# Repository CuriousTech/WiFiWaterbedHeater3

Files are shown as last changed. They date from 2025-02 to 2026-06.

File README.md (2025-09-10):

# WiFi Waterbed Heater 3 (final)

This is the 3rd and final iteration of this. The GUI is based on my [Universal Remote](https://github.com/CuriousTech/Smart-Universal-Remote) so it has a multi-tile swap gesture interface using the
[WaveShare-ESP32-S3-Touch-LCD-2.8](https://www.waveshare.com/wiki/ESP32-S3-Touch-LCD-2.8).  
  
wb3  
  
The small breakout board is not really needed and uses more space since the only component required is a 4K7 resistor to pull up the DS18B20 signal line, but I already have connectors for everything from the old project. So from left to right: DS18B20, power/slave, LD2410, and AM2320/AM2322 vertically.  The i2c lines have internal pullups.  
  
WBBOB  
  
The slave board and 3D files from the WB2 project is reposted here as well.  
  
3D  

The web page. Same as previous, but allows drag and drop files over the lower file display areas. The internal files are only used for click and notifications sounds so far. It's just easier than setting up to upload the FFat.  Although SPIFFS or LittleFS can be used instead very easily. The SD card is used for the MP3 player.  
  
Web  
  
Building: The ino explains the common settings for the IDE like my other projects. I use the Windows Store version because it works best for me. If a library is missing, the error should show a line with a link to where to get it. If not, complain.  
  
A little explanation of the HLK-LD2450 reader: The bottom area of the page represents the detection area. The 5000 (mm) is the X (signed X/2) and Y cutoff. Anything beyond that is zone 2 (outside the room). Zone 2 is also anything painted grey (this sees through walls). This area means lights/fan off. Zome 1 is in the room/lights on and fan off, motion or not. Latch area switches to zone 0/light off and fan on. Hold area is still in bed/zone 0 if latched.

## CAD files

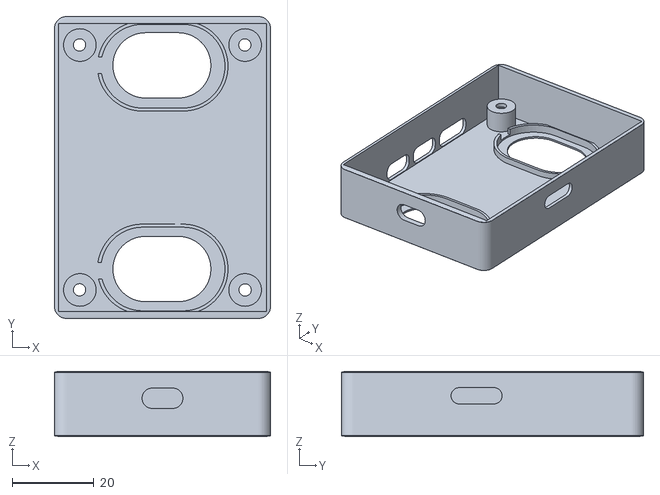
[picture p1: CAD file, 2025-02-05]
3D/WaveShare28wb.stl
53.0 x 74.0 x 16.0

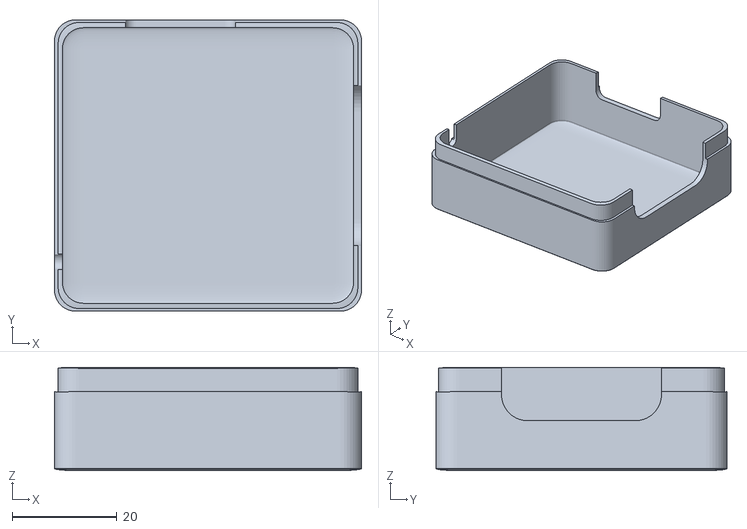
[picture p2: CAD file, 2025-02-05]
3D/Slave Bottom.stl
58.5 x 55.5 x 19.7

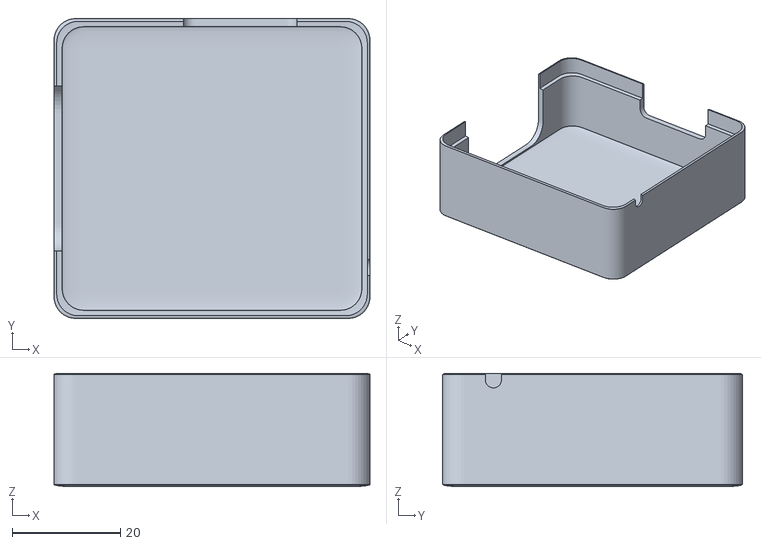
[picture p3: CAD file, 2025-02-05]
3D/Slave Top.stl
58.5 x 55.5 x 21.0

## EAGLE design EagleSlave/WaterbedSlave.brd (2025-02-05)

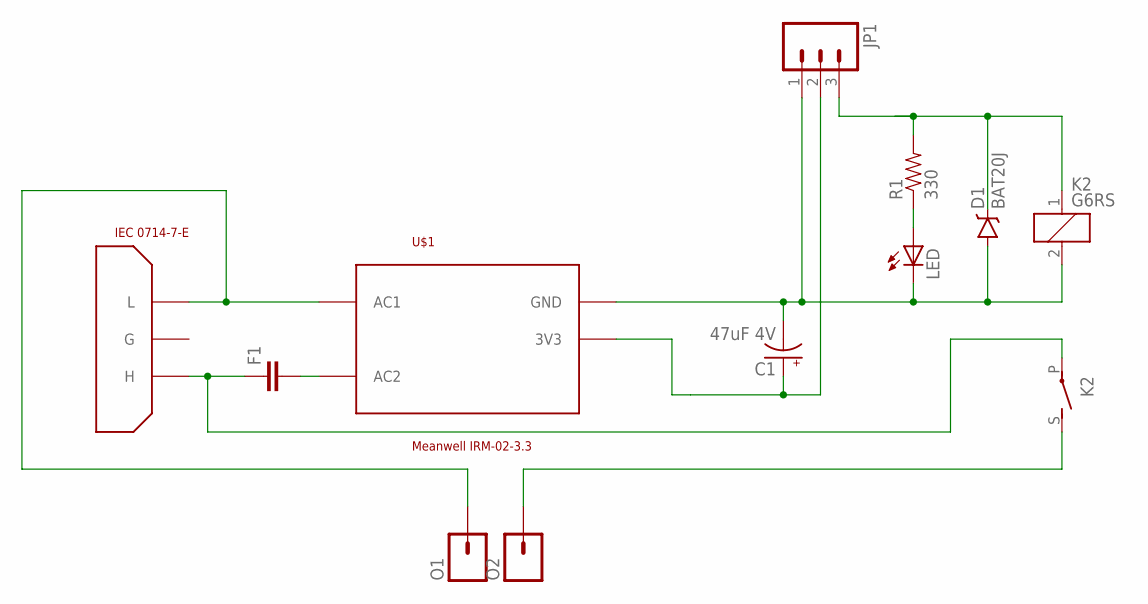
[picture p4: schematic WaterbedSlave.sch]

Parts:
C1: 47uF 4V; CPOL-RADIAL-10UF-25V
D1: BAT20J; SOD-323
F1: CAPPTH1; CAP-PTH-5MM
JP1: M03POLAR_LOCK; MOLEX-1X3_LOCK
K2: G6RS
LED: LEDCHIPLED_0805; CHIPLED_0805
O1, O2: M01PTH_2MM; 1X01_2MM
R1: 330; 0805
U$1: Meanwell IRM-02-3.3; RAC02-3.3SC
U$3: IEC 0714-7-E; IEC

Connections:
3V3: C1.1 (+), JP1.2, U$1.GND (3V3)
GND: C1.2 (-), D1.A, JP1.1, K2.2, LED.C, U$1.3V3 (GND)
unnamed: O1.1, U$1.AC1, U$3.L
unnamed: F1.2, U$1.AC2
unnamed: K2.S, O2.1
unnamed: F1.1, K2.P, U$3.H
unnamed: LED.A, R1.1
unnamed: D1.C, JP1.3, K2.1, R1.2

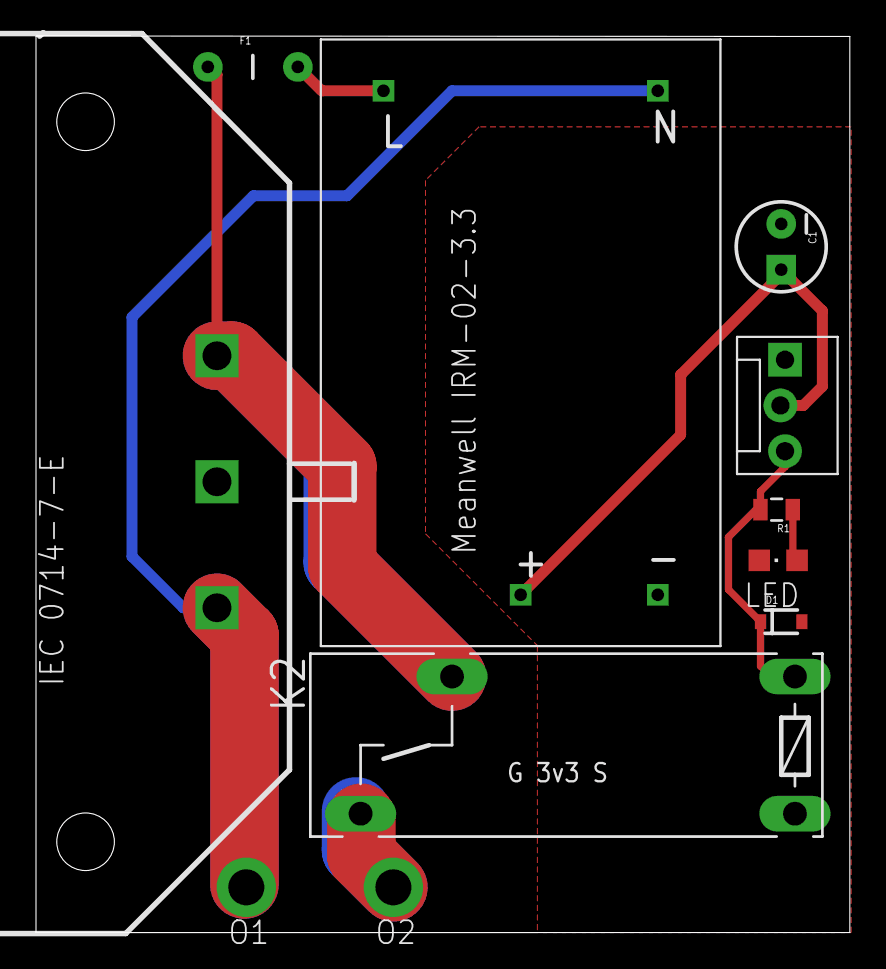
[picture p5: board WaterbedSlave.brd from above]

Board: 2 copper layers, 45.2 x 49.8 mm, 11 parts (0 on the bottom side), 8 nets.

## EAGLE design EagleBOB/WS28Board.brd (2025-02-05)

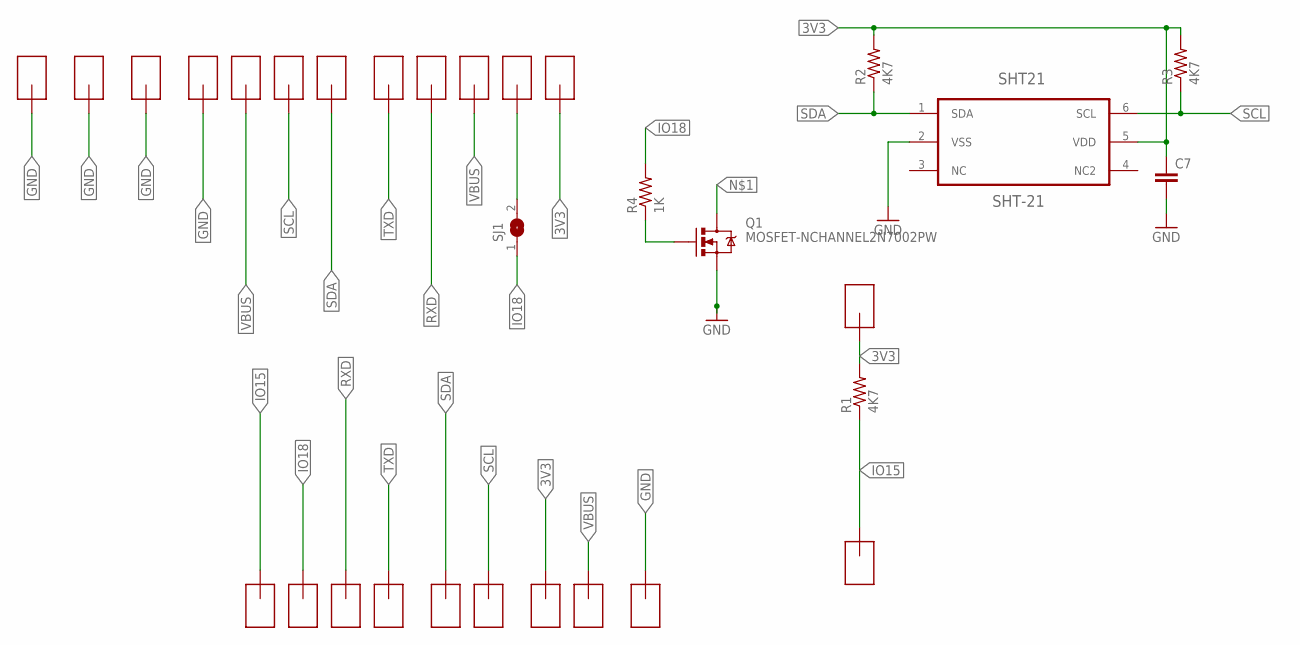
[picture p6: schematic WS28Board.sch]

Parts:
C7: CAP0603-CAP; 0603-CAP
GND, GND1, GND2, GND3, GND4: SMD-PAD1
Q1: MOSFET-NCHANNEL2N7002PW; SOT323
R1, R2, R3: 4K7; 0805
R4: 1K; 0805
SHT21: SHT-21; SHT21
SJ1: SJ
U$1, U$2, U$3, U$4, U$5, U$6, U$7, U$8, U$9, U$10, U$11, U$12, U$13, U$14, U$15, U$16, U$17, U$18: SMD-PAD1

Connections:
3V3: C7.1, GND4.>NAME, R1.2, R2.2, R3.2, SHT21.5 (VDD), U$13.>NAME, U$14.>NAME
GND: C7.2, Q1.2 (S), SHT21.2 (VSS), U$1.>NAME, U$10.>NAME, U$15.>NAME, U$16.>NAME, U$17.>NAME
IO15: GND2.>NAME, R1.1, U$18.>NAME
IO18: R4.2, SJ1.1, U$9.>NAME
unnamed: GND.>NAME, Q1.3 (D), SJ1.2
unnamed: Q1.1 (G), R4.1
NC: SHT21.3 (NC)
RXD: U$3.>NAME, U$8.>NAME
SCL: R3.1, SHT21.6 (SCL), U$6.>NAME, U$12.>NAME
SDA: GND1.>NAME, GND3.>NAME, R2.1, SHT21.1 (SDA)
TXD: U$2.>NAME, U$7.>NAME
VBUS: U$4.>NAME, U$5.>NAME, U$11.>NAME

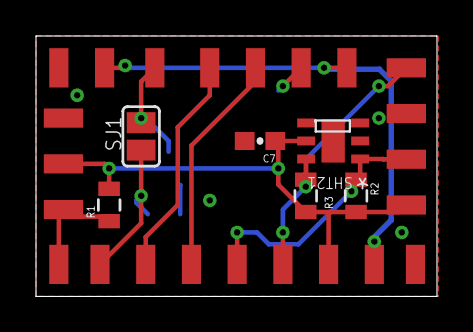
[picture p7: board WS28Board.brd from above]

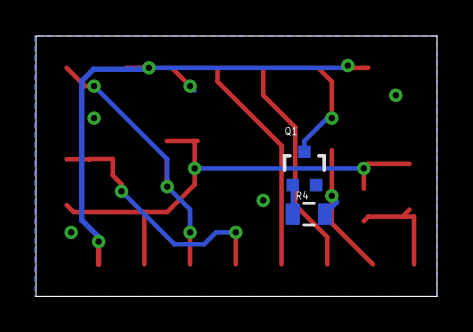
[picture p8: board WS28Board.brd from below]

Board: 2 copper layers, 22.3 x 14.5 mm, 31 parts (2 on the bottom side), 11 nets.

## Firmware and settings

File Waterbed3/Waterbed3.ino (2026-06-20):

/**The MIT License (MIT)

Copyright (c) 2024 by Greg Cunningham, CuriousTech

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
THE SOFTWARE IS PROVIDED "AS IS", WITHOUT WARRANTY OF ANY KIND, EXPRESS OR
IMPLIED, INCLUDING BUT NOT LIMITED TO THE WARRANTIES OF MERCHANTABILITY,
FITNESS FOR A PARTICULAR PURPOSE AND NONINFRINGEMENT. IN NO EVENT SHALL THE
AUTHORS OR COPYRIGHT HOLDERS BE LIABLE FOR ANY CLAIM, DAMAGES OR OTHER
LIABILITY, WHETHER IN AN ACTION OF CONTRACT, TORT OR OTHERWISE, ARISING FROM,
OUT OF OR IN CONNECTION WITH THE SOFTWARE OR THE USE OR OTHER DEALINGS IN THE
SOFTWARE.
*/

// Build with Arduino IDE 1.8.57.0
//  ESP32: (2.0.14, NOT 2.0.17) ESP32S3 Dev Module, QIO, CPU Freq: 240MHz for mp3 playback
//  Flash: 16MB
//  Partition: 8M with SPIFFS or 16 MB with FatFS (change INTERNAL_FS in Media.h to match)
//  PSRAM: OPI PSRAM
//  In TFT_eSPI/User_Setup_Select.h use #include <User_Setups/Setup303_Waveshare_ESP32S3_ST7789.h> (custom, included in repo)

#include <WiFi.h>
#include <time.h>
#include "eeMem.h"
#include "WB.h"
#include "TempArray.h"
#include "THSensor.h"
#include "Media.h"

#include <ESPmDNS.h>
#include <ArduinoOTA.h>

#include <ESPAsyncWebServer.h> // https://github.com/ESP32Async/ESPAsyncWebServer (3.7.2)
#include <JsonParse.h> // https://github.com/CuriousTech/ESP-HVAC/tree/master/Libraries/JsonParse
#include "jsonString.h"
#include "pages.h"

AsyncWebServer server( 80 );
AsyncWebSocket ws("/ws"); // access at ws://[esp ip]/ws
int WsClientID;
int WsPcClientID;
void jsonCallback(int16_t iName, int iValue, char *psValue);
JsonParse jsonParse(jsonCallback);
bool bKeyGood;
IPAddress lastIP;
int nWrongPass;
TempArray ta;
THSensor ths;
Media media;
tm gLTime;

#define TZ  "EST5EDT,M3.2.0,M11.1.0"  // https://github.com/nayarsystems/posix_tz_db/blob/master/zones.csv

#include "display.h"
#include "Lights.h" // Uses ~3KB
 
#ifdef RADAR_H // defined in WB.h
Radar radar;
#endif

Lights lights;
const char *hostName = "WaterbedM"; // Device and OTA name

bool bConfigDone = false; // EspTouch done or creds set
bool bStarted = false; // first start
bool bRestarted = false; // consecutive restarts

Display display;
eeMem ee;
WB wb;

void consolePrint(String s)
{
  jsonString js("print");
  js.Var("text", s);
  ws.textAll(js.Close());
}

void WsSend(String s)
{
  ws.textAll(s);
}

bool secondsWiFi() // called once per second
{
  bool bConn = false;

  if(!bConfigDone)
  {
    if( WiFi.smartConfigDone())
    {
      bConfigDone = true;
    }
  }
  if(bConfigDone)
  {
    if(WiFi.status() == WL_CONNECTED)
    {
      if(!bStarted)
      {
        MDNS.begin( hostName );
        bStarted = true;
        MDNS.addService("iot", "tcp", 80);
        WiFi.SSID().toCharArray(ee.szSSID, sizeof(ee.szSSID)); // Get the SSID from SmartConfig or last used
        WiFi.psk().toCharArray(ee.szSSIDPassword, sizeof(ee.szSSIDPassword) );
        lights.init();
        bConn = true;
      }
      if(!bRestarted) // wakeup work if needed
      {
        bRestarted = true;
      }
    }
    else if(WiFi.status() == WL_DISCONNECTED) // connection dropped
    {
        static uint8_t nDelay = 5;
        if(--nDelay == 0)
        {
          WiFi.begin(ee.szSSID, ee.szSSIDPassword);
          nDelay = 5;
        }
    }
    else if(WiFi.status() == WL_CONNECT_FAILED) // failed to connect for some reason
    {
      WiFi.mode(WIFI_AP_STA);
      WiFi.beginSmartConfig();
      bConfigDone = false;
      bStarted = false;
    }
  }

  if(WiFi.status() != WL_CONNECTED)
    return bConn;

  return bConn;
}

// Currently using PC to relay
bool sendStatCmd( uint16_t *pCode)
{
  display.RingIndicator(2);
  jsonString js("STAT");
  js.Var("value", pCode[0]);
  WsSend(js.Close());
  return true;
}

const char *jsonListCmd[] = {
  "key",
  "TZ",
  "avg",
  "cnt",
  "tadj",
  "ppkwh",
  "vaca",
  "vacatemp",
  "I",
  "N",
  "S", // 10
  "T",
  "H",
  "watts",
  "save",
  "aadj",
  "eco",
  "outtemp",
  "outrh",
  "notif",
  "notifCancel", // 20
  "rate",
  "hostip",
  "lightip",
  "music",
  "restart",
  "ST",
  "STATTEMP",
  "STATSETTEMP",
  "STATFAN",
  "setfs", // 30
  "cd",
  "delf",
  "createdir",
  "radarpts",
  "blindbits",
  "bound",
  NULL
};

// this is for the web page, and needs to be seperated from the PC client
void jsonCallback(int16_t iName, int iValue, char *psValue)
{
  if (!bKeyGood && iName)
  {
    if (nWrongPass == 0)
      nWrongPass = 10;
    else if ((nWrongPass & 0xFFFFF000) == 0 ) // time doubles for every high speed wrong password attempt.  Max 1 hour
      nWrongPass <<= 1;
    return; // only allow for key
  }

  char *p, *p2;
  static int item = 0;

  switch (iName)
  {
    case 0: // key
      if (!strcmp(psValue, ee.iotPassword)) // first item must be key
        bKeyGood = true;
      break;
    case 1: // TZ
      break;
    case 2: // avg
      ee.bAvg = iValue;
      break;
    case 3: // cnt
      ee.schedCnt[wb.m_season] = constrain(iValue, 1, 8);
      ws.textAll(setupJson()); // update all the entries
      break;
    case 4: // tadj
      wb.changeTemp(iValue, false);
      ws.textAll(setupJson()); // update all the entries
      break;
    case 5: // ppkw
      ee.ppkwh = iValue;
      break;
    case 6: // vaca
      ee.bVaca = iValue;
      break;
    case 7: // vacatemp
      if (ee.bCF)
        ee.vacaTemp = constrain( (int)(atof(psValue) * 10), 70, 270); // 7-27C
      else
        ee.vacaTemp = constrain( (int)(atof(psValue) * 10), 450, 800); // 45-80F
      break;
    case 8: // I
      item = iValue;
      break;
    case 9: // N
      break;
    case 10: // S
      p = strtok(psValue, ":");
      p2 = strtok(NULL, "");
      if (p && p2) {
        iValue *= 60;
        iValue += atoi(p2);
      }
      ee.schedule[wb.m_season][item].timeSch = iValue;
      break;
    case 11: // T
      ee.schedule[wb.m_season][item].setTemp = atof(psValue) * 10;
      break;
    case 12: // H
      ee.schedule[wb.m_season][item].thresh = (int)(atof(psValue) * 10);
      wb.checkLimits();      // constrain and check new values
      wb.checkSched(true);   // reconfigure to new schedule
      break;
    case 13: // watts
      ee.watts = iValue;
      break;
    case 14: // save
      ee.update(false);
      break;
    case 15: // aadj
      wb.changeTemp(iValue, true);
      ws.textAll(setupJson()); // update all the entries
      break;
    case 16: // eco
      ee.bEco = iValue ? true : false;
      wb.setHeat();
      break;
    case 17: // outtemp
      display.m_outTemp = iValue;
      break;
    case 18: // outrh
      display.m_outRh = iValue;
      break;
    case 19: // notif
      display.Notify(psValue, lastIP);
      break;
    case 20: // notifCancel
      display.NotificationCancel(lastIP);
      break;
    case 21: // rate
      if (iValue == 0)
        break; // don't allow 0
      ee.rate = iValue;
      sendState();
      break;
    case 22: // host IP / port  (call from host with ?hostip=80)
      ee.hostIp[0] = lastIP[0];
      ee.hostIp[1] = lastIP[1];
      ee.hostIp[2] = lastIP[2];
      ee.hostIp[3] = lastIP[3];
      ee.hostPort = iValue ? iValue : 80;
      break;
    case 23: // lightIP
      {
        IPAddress ip;
        ip.fromString(psValue);
        ee.lights[0].ip[0] = ip[0];
        ee.lights[0].ip[1] = ip[1];
        ee.lights[0].ip[2] = ip[2];
        ee.lights[0].ip[3] = ip[3];
      }
      break;
    case 24: // music
      media.Play("/", psValue);
      break;
    case 25: // restart
      ESP.restart();
      break;
    case 26: // ST
      ee.sleepTime = iValue;
      break;
    case 27: // STATTEMP
      display.m_statTemp = iValue;
      break;
    case 28: // STATSETTEMP
      display.m_statSetTemp = iValue;
      break;
    case 29: // STATFAN
      display.m_bStatFan = iValue;
      break;

    case 30: // setfs
      media.setFS(psValue);
      ws.textAll(setupJson()); // update FS and disk free
      break;
    case 31: // cd
      media.setPath(psValue);
      break;
    case 32: // delf
      media.deleteFile(psValue);
      ws.textAll(setupJson()); // update disk free
      break;
    case 33: // createdir
      media.createDir(psValue);
      ws.textAll(setupJson()); // update disk free
      break;
    case 34: // radarpts
      parseRadarPoints(psValue);
      break;
    case 35: // blindbits
      parseBlindbits(psValue);
      break;
    case 36: // bound
      ee.bound = constrain(iValue, 1000, 12000);
      break;
  }
}

void parseRadarPoints(char *p)
{
  char *token = strtok(p, ",");

  for(uint8_t n = 0; token && n < 8; n++)
  {
    ee.radarPts[n][0] = atoi(token);
    token = strtok(NULL, ",");
    if(token)
      ee.radarPts[n][1] = atoi(token);
    token = strtok(NULL, ",");
  }
}

void parseBlindbits(char *p)
{
  char *token = strtok(p, ",");

  for(uint8_t n = 0; token && n < 32; n++)
  {
    ee.blindBits[n] = atoi(token);
    token = strtok(NULL, ",");
  }
}

void parseParams(AsyncWebServerRequest *request)
{
  int16_t val;

  if (nWrongPass && request->client()->remoteIP() != lastIP) // if different IP drop it down
    nWrongPass = 10;

  lastIP = request->client()->remoteIP();

  for ( uint8_t i = 0; i < request->params(); i++ )
  {
    const AsyncWebParameter* p = request->getParam(i);
    String s = request->urlDecode(p->value());

    uint8_t idx;
    for (idx = 0; jsonListCmd[idx]; idx++)
      if ( p->name().equals(jsonListCmd[idx]) )
        break;
    if (jsonListCmd[idx] == NULL)
      return;
    int iValue = s.toInt();
    if (s == "true") iValue = 1;

    jsonCallback(idx, iValue, (char *)s.c_str());
  }
}

void startWiFi()
{
  if(WiFi.status() == WL_CONNECTED)
    return;

  WiFi.setSleep(false);

  WiFi.hostname(hostName);
  WiFi.mode(WIFI_STA);

  if ( ee.szSSID[0] )
  {
    WiFi.begin(ee.szSSID, ee.szSSIDPassword);
    WiFi.setHostname(hostName);
    bConfigDone = true;
  }
  else
  {
    IPAddress ip;
    WiFi.beginSmartConfig();
    display.Notify("Use EspTouch to configure\nWiFi connection", ip);
  }

  ArduinoOTA.setHostname(hostName);
  ArduinoOTA.begin();
  ArduinoOTA.onStart([]() {
    IPAddress ip;
    display.toast("OTA Update");
    ee.update(false);
    consolePrint("OTA Update Started");
    delay(100);
  });

  static bool bInit = false;
  if(!bInit)
  {
    bInit = true;
    ws.onEvent(onWsEvent);
    server.addHandler(&ws);

    server.on ( "/", HTTP_GET | HTTP_POST, [](AsyncWebServerRequest * request)
    {
      parseParams(request);
      if(INTERNAL_FS.exists("/index.html")) // override the hard coded page
          request->send(INTERNAL_FS, "/index.html");
      else
        request->send_P( 200, "text/html", index_page);
    });

    server.on ( "/fm.html", HTTP_GET | HTTP_POST, [](AsyncWebServerRequest * request)
    {
      request->send_P( 200, "text/html", fileman);
    });

    server.on ( "/upload", HTTP_POST, [](AsyncWebServerRequest * request)
    {
      request->send( 200);
      ws.textAll(setupJson()); // update free space
    },
    [](AsyncWebServerRequest *request, String filename, size_t index, uint8_t *data, size_t len, bool final)
     {
      if(!index)
        request->_tempFile = media.createFile(filename);
      if(len)
       request->_tempFile.write(data, len);
      if(final)
        request->_tempFile.close();
     }
    );

    server.on ( "/s", HTTP_GET | HTTP_POST, [](AsyncWebServerRequest * request)
    {
      parseParams(request); // no repsonse, just take params
      request->send(200, "text/plain", "OK");
    });

    server.onNotFound([](AsyncWebServerRequest * request) { // make it quiet to the outside world
//      request->send(404);
    });

    server.on("/heap", HTTP_GET, [](AsyncWebServerRequest * request) { // just for checking
      request->send(200, "text/plain", String(ESP.getFreeHeap()));
    });
  
    server.on("/favicon.ico", HTTP_GET, [](AsyncWebServerRequest * request) {
      AsyncWebServerResponse *response = request->beginResponse_P(200, "image/x-icon", favicon, sizeof(favicon));
      response->addHeader("Content-Encoding", "gzip");
      request->send(response);
    });

    server.on("/del-btn.png", HTTP_GET, [](AsyncWebServerRequest *request){
      AsyncWebServerResponse *response = request->beginResponse_P(200, "image/png", delbtn_png, sizeof(delbtn_png));
      request->send(response);
    });

    server.serveStatic("/", INTERNAL_FS, "/");
    server.serveStatic("/sd", SD_MMC, "/");

    server.begin();
    jsonParse.setList(jsonListCmd);
  }
}

void serviceWiFi()
{
// Handle OTA server.
  ArduinoOTA.handle();
}

String dataJson()
{
  jsonString js("state");
  js.Var("t", (long)time(nullptr) );

  js.Var("waterTemp", String((float)wb.m_currentTemp / 10, 1) );
  js.Var("setTemp", String((float)ee.schedule[wb.m_season][wb.m_schInd].setTemp / 10, 1) );
  js.Var("hiTemp",  String((float)wb.m_hiTemp / 10, 1) );
  js.Var("loTemp",  String((float)wb.m_loTemp / 10, 1) );
  js.Var("on",   wb.m_bHeater);
  js.Var("temp", String((float)ths.m_temp / 10, 1) );
  js.Var("rh",   String((float)ths.m_rh / 10, 1) );
  js.Var("c",    String((ee.bCF) ? "C" : "F"));
#ifdef RADAR_H
  js.Var("zone", radar.nZone);
  js.Var("dist", radar.nDistance);
  js.Var("ener", radar.nEnergy);
#endif
  js.Var("eta",  wb.nHeatETA);
  js.Var("cooleta",  wb.nCoolETA);

  return js.Close();
}

void remoteNotifCancelled()
{
  if(!display.m_nWsConnected)
    return;

  jsonString js("notif");
  js.Var("data", 0 );
  ws.textAll( js.Close() );
}

uint8_t ssCnt = 26;

void sendState()
{
  if (display.m_nWsConnected)
    ws.textAll( dataJson() );
  ssCnt = 58;
}

String setupJson()
{
  jsonString js("settings");
  js.Var("st", ee.sleepTime);
  js.Var("vt", String((float)ee.vacaTemp / 10, 1) );
  js.Var("avg", ee.bAvg);
  js.Var("ppkwh", ee.ppkwh);
  js.Var("vo",  ee.bVaca);
  js.Var("idx", wb.m_schInd);
  js.Array("cnt", ee.schedCnt, 4);
  js.Var("w",  ee.watts);
  js.Var("r",  ee.rate);
  js.Var("e",  ee.bEco);
  js.Var("season", wb.m_season);
  js.Array("item", ee.schedule, 4);
  js.Array("seasonDays", ee.scheduleDays, 4);
  js.Array("ts", ee.tSecsMon, 12);
  js.Var("diskfree",  media.freeSpace() );
  js.Var("sdavail",  media.SDCardAvailable() );
  js.Var("currfs", media.currFS());
  js.ArrayPts("radarpts", ee.radarPts, 8);
  js.Array("blindbits", ee.blindBits, 32);
  js.Var("bound", ee.bound);
  return js.Close();
}

void onWsEvent(AsyncWebSocket * server, AsyncWebSocketClient * client, AwsEventType type, void * arg, uint8_t *data, size_t len)
{ //Handle WebSocket event

  switch (type)
  {
    case WS_EVT_CONNECT:      //client connected
      client->text( setupJson() );
      client->text( dataJson() );
      client->text( ta.get() );
      display.m_nWsConnected++;
      WsClientID = client->id();
      media.setPath("/"); // trigger file list send
      break;
    case WS_EVT_DISCONNECT:    //client disconnected
      if (display.m_nWsConnected)
        display.m_nWsConnected--;
      WsClientID = 0;
      if(client->id() == WsPcClientID)
        WsPcClientID = 0;
      break;
    case WS_EVT_ERROR:    //error was received from the other end
      break;
    case WS_EVT_PONG:    //pong message was received (in response to a ping request maybe)
      break;
    case WS_EVT_DATA:  //data packet
      AwsFrameInfo * info = (AwsFrameInfo*)arg;
      if (info->final && info->index == 0 && info->len == len) {
        //the whole message is in a single frame and we got all of it's data
        if (info->opcode == WS_TEXT) {
          data[len] = 0;
          jsonParse.process((char *)data);
        }
      }
      break;
  }
}

void setup()
{
//  delay(1000);
//  ets_printf("\nStarting\n"); // print over USB (sets baud rate to 115200, radar needs 256K)

  media.init(); // Starts FS for ee
  ee.init();  // Load EE
  display.init(); // start display
  wb.init(); // start WB
  ths.init(); // Start temp sensor
  startWiFi();
#ifdef RADAR_H
  radar.init();
#endif
}

void loop()
{
  static uint8_t hour_save, min_save = 255, mon_save = 255;

  display.service();  // check for touch, etc.
  media.service();
  lights.service();

#ifdef RADAR_H
  radar.service();
#endif

  serviceWiFi(); // handles OTA

  static uint32_t lastMS;

  if(millis() - lastMS > 1000) // only do stuff once per second
  {
    getLocalTime(&gLTime); // this is used globally
    
    lastMS = millis();
    if(secondsWiFi()) // once per second stuff, returns true once on connect
    {
      configTime(0, 0, "pool.ntp.org");
      setenv("TZ", TZ, 1);
      tzset();
    }

    display.oneSec();

    if(gLTime.tm_year > 124)
    {
      if(min_save != gLTime.tm_min) // only do stuff once per minute
      {
        min_save = gLTime.tm_min;
        wb.checkSched(false);     // check every minute for next schedule
  
        if(hour_save != gLTime.tm_hour) // update our IP and time daily (at 2AM for DST)
        {
          hour_save = gLTime.tm_hour;
          if(hour_save == 2 && WiFi.status() == WL_CONNECTED)
          {
            configTime(0, 0, "pool.ntp.org");
            setenv("TZ", TZ, 1);
            tzset();
          }

          ee.update(false);
  
          if ( mon_save != gLTime.tm_mon )
          {
            if (mon_save <= 12) // restart check
              ee.tSecsMon[gLTime.tm_mon - 1] = 0;
            mon_save = gLTime.tm_mon;
          }
          wb.getSeason();
        }
      }
      IPAddress ip(ee.hvacIP);
      lights.callQueue(ip, 80, "/s");

      if( (min_save % 5) == 0)
        ta.add(); // 5 minute log
    }

    if (--ssCnt == 0) // keepalive
      sendState();

    if (nWrongPass)
      nWrongPass--;

    wb.service();
    ths.service();
  }
}

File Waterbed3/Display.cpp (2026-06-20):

/*
Display and UI code
*/

#include <WiFi.h>
#include <time.h>
#include "eeMem.h"
#include "Lights.h"
#include <FunctionalInterrupt.h>
#include "display.h"
#include <math.h>
#include "WB.h"
#include "TempArray.h"
#include "THSensor.h"
#include "Media.h"

TFT_eSPI tft = TFT_eSPI();
TFT_eSprite sprite = TFT_eSprite(&tft);
TFT_eSprite popup = TFT_eSprite(&tft);

// URemote functions
extern int WsPcClientID;
extern void stopWiFi();
extern void startWiFi();
extern bool sendStatCmd( uint16_t *pCode);
extern void consolePrint(String s); // for browser debug
extern void remoteNotifCancelled(void);

extern tm gLTime;

static_assert(USER_SETUP_ID==303, "User setup incorrect in TFT_eSPI, use 303");

#define I2C_SDA  11
#define I2C_SCL  10
#define TP_SDA    1
#define TP_SCL    3
#define IMU_INT  13 // INT1
#define TP_RST    2
#define TP_INT    4 // normally high
#define TFT_BL    5
#define PWR_CTRL  7
#define PWR_BTN   6

#include "CST328.h"
CST328 touch(TP_SDA, TP_SCL, TP_RST, TP_INT);

const int16_t bgColor = TFT_BLACK;

#define TITLE_HEIGHT 22
#define BORDER_SPACE 3 // H and V spacing + font size for buttons and space between buttons

void Display::init(void)
{
  pinMode(TFT_BL, OUTPUT);

  pinMode(PWR_CTRL, OUTPUT);
  digitalWrite(PWR_CTRL, HIGH);

  tft.init();
  tft.setRotation(1);
  tft.setTextPadding(8);

  sprite.createSprite(DISPLAY_WIDTH, DISPLAY_HEIGHT); // This uses over 115K RAM for 240x240
  popup.setTextDatum(TL_DATUM);
  popup.setTextColor(TFT_WHITE, TFT_DARKGREY );
  popup.setFreeFont(&FreeSans9pt7b);

  // count tiles, index rows, count columns, format the buttons
  uint8_t nRowIdx = 0;

  for(m_nTileCnt = 0; m_nTileCnt < TILES && (m_tile[m_nTileCnt].Extras || m_tile[m_nTileCnt].pszTitle || m_tile[m_nTileCnt].pBGImage); m_nTileCnt++) // count screens
  {
    if(m_tile[m_nTileCnt].nRow != nRowIdx)
      m_nRowStart[++nRowIdx] = m_nTileCnt;
    m_nColCnt[nRowIdx]++;
    formatButtons(m_tile[m_nTileCnt]);
  }

  m_nCurrTile = 2; // start on WB tile
  m_nCurrRow = m_tile[m_nCurrTile].nRow;
  drawTile(m_nCurrTile, true, 0, 0);
  sprite.pushSprite(0, 0); // draw starting tile

  touch.begin();
}

void Display::service(void)
{
  dimmer();

  if(m_nDispFreeze)
  {
    if( millis() < m_nDispFreeze) // freeze display for notification
      return;
    m_nDispFreeze = 0;
  }

  static bool bScrolling; // scrolling active
  static bool bSliderHit;
  static int16_t touchXstart, touchYstart; // first touch pos for scolling and non-moving detect
  static uint32_t touchStartMS; // timing for detecting swipe vs press

  if(touch.available() )
  {
    if(touch.event == 0) // initial touch. Just setup for gesture check
    {
      touchXstart = touch.x;
      touchYstart = touch.y;
      touch.gestureID = 0;
      bSliderHit = false;
      bScrolling = false;
      touchStartMS = millis();

      m_backlightTimer = ee.sleepTime; // reset timer for any touch
      m_brightness = ee.brightLevel;
    }
    else if(touch.event == 1) // release
    {
      if(touch.gestureID)
      {
        snapTile(); // finish the swipe (only forward for now)
        m_bSwipeReady = false;
        touch.gestureID = 0; // unlock the idle display updates
      }
      else if(m_pCurrBtn)
      {
        drawButton(m_tile[m_nCurrTile], m_pCurrBtn, false, 0, 0, false); // draw released button
        updateTile();

        if(m_pCurrBtn && (m_pCurrBtn->flags & (BF_SLIDER_H|BF_SLIDER_V)) )
        {
          buttonCmd(m_pCurrBtn, true);
        }
      }
      else if(bScrolling == false) // check for a quick button hit if nothing else appeared to happen
      {
        checkButtonHit(touchXstart, touchYstart);
      }

      touch.gestureID = 0;
      m_pCurrBtn = NULL;
    }
    else // 2=active
    {
      if( m_brightness < ee.brightLevel ) // ignore input until brightness is full
        return;

      Tile& pTile = m_tile[m_nCurrTile];

      if(bSliderHit);
      else if(touch.gestureID) // swiping mode
      {
        swipeTile(touch.x - touchXstart, touch.y - touchYstart);
        touchXstart = touch.x;
        touchYstart = touch.y;
      }
      else if(bScrolling) // scrolling detected
      {
        if(touch.y - touchYstart)
          bScrolling = scrollPage(m_nCurrTile, touch.y - touchYstart);
        touchYstart = touch.y;
      }
      else // normal press or hold
      {
        if( !m_bPopupActive && pTile.Extras & EX_SCROLL ) // give this a bit more priority
        {
          if( touchYstart > 40 && touchYstart < DISPLAY_HEIGHT - 40 && touch.y != touchYstart && (touch.y - touchYstart < 10 || touchYstart - touch.y < 10)) // slow/short flick
          {
            if( touchXstart > 40 && touchXstart < DISPLAY_WIDTH - 40) // start needs to be in the middle somewhere
            {
              bScrolling = scrollPage(m_nCurrTile, touch.y - touchYstart); // test it
              touchYstart = touch.y;
            }
          }
        }

        if(millis() - touchStartMS < 150 && touch.gestureID == 0 && bScrolling == false) // delay a bit
        {
          if(m_bPopupActive && touch.x >= m_popupLeft && touch.x < m_popupLeft + m_popupWidth && touch.y >= m_popupTop && touch.y < m_popupTop + m_popupHeight)
          {
            m_bPopupActive = false;
            if(m_notifyIp)
              remoteNotifCancelled();
            updateTile();
          }
          else
          { // detect swipes
            swipeCheck((int16_t)touch.x - (int16_t)touchXstart, (int16_t)touch.y - (int16_t)touchYstart);

            if(touch.gestureID)
              startSwipe();
          }
        }
        else if(m_pCurrBtn == NULL && touch.gestureID == 0 && bScrolling == false) // check button hit
        {
          if(m_bPopupActive && touch.x >= m_popupLeft && touch.x < m_popupLeft + m_popupWidth && touch.y >= m_popupTop && touch.y < m_popupTop + m_popupHeight)
          {
            m_bPopupActive = false;
            if(m_notifyIp)
              remoteNotifCancelled();
            updateTile(); // erase popup
          }
          else
          {
            checkButtonHit(touchXstart, touchYstart);
          }
        }
        else if(m_pCurrBtn && (m_pCurrBtn->flags & (BF_SLIDER_H|BF_SLIDER_V)) )
        {
          if(m_pCurrBtn->flags & BF_SLIDER_H)
          {
            uint16_t off = constrain(touch.x - m_pCurrBtn->r.x, 0, m_pCurrBtn->r.w);
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

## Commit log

2025-02-14 Double row lights tile, fixed notification history
    [Display.cpp]
2025-02-14 Full name based switch calls
2025-09-07 Changed to esp32 time lib
2025-09-07 Current item highlight
2025-09-07 Changed to esp32 time lib, better wifi reconnect
2026-06-20 Updated T&H for int version lib
    Updated temperature and humidity measurement logic to use int16_t and adjusted conversion for temperature.

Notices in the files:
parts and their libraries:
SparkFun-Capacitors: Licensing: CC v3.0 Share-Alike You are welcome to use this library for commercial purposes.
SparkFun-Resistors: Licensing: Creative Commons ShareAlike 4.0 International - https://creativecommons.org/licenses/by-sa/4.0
